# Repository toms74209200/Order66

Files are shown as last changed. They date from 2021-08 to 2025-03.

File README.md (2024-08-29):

Order66

<h1 style="text-align: center; margin-top: 0; margin-bottom: 7rem; border-bottom: none;">Order66 - 日本語入力のための60%キーボード</h1>

- 66 keys
- Cherry MX/Kailh Choc/Kailh Choc V2 key switch compatible
- USB type-C (USB2.0) interface
- On-Board CPU(ATmega32U4)

## Layout

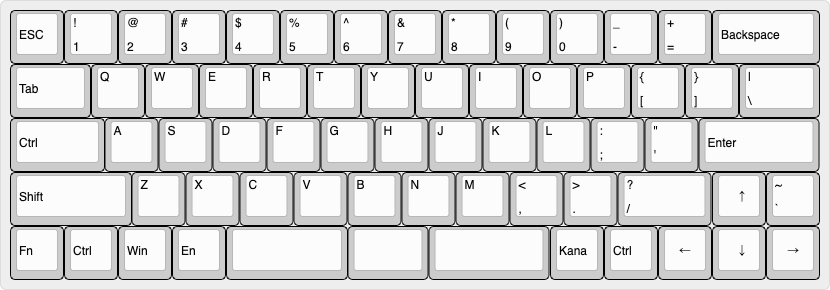
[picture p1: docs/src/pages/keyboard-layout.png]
layout


Designed in [Keyboard-layout-editor.com](http://www.keyboard-layout-editor.com).

## License

MIT License

## Author

[toms74209200](<https://github.com/toms74209200>)

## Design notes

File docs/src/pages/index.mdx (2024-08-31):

---
layout: ../layouts/Layout.astro
title: Order66 - 日本語入力のための60%キーボード
---
import { Image } from 'astro:assets';

import logoOrder66 from './logo_order66.svg';
import keyboardLayout from './keyboard-layout.png';
import landingImage from '../../public/landingview.webp';

<Image src={logoOrder66} alt="Order66" width={keyboardLayout.width} style="max-width: 100%;" />

<div style="max-width: 100%;">
  <h1 style="text-align: center; margin-top: 0; margin-bottom: 5rem">Order66 - 日本語入力のための60%キーボード</h1>
</div>

<div style="margin-top: 3rem; margin-bottom: 5rem;">
  サンプル画像
</div>

## キーマップ

キーマップ

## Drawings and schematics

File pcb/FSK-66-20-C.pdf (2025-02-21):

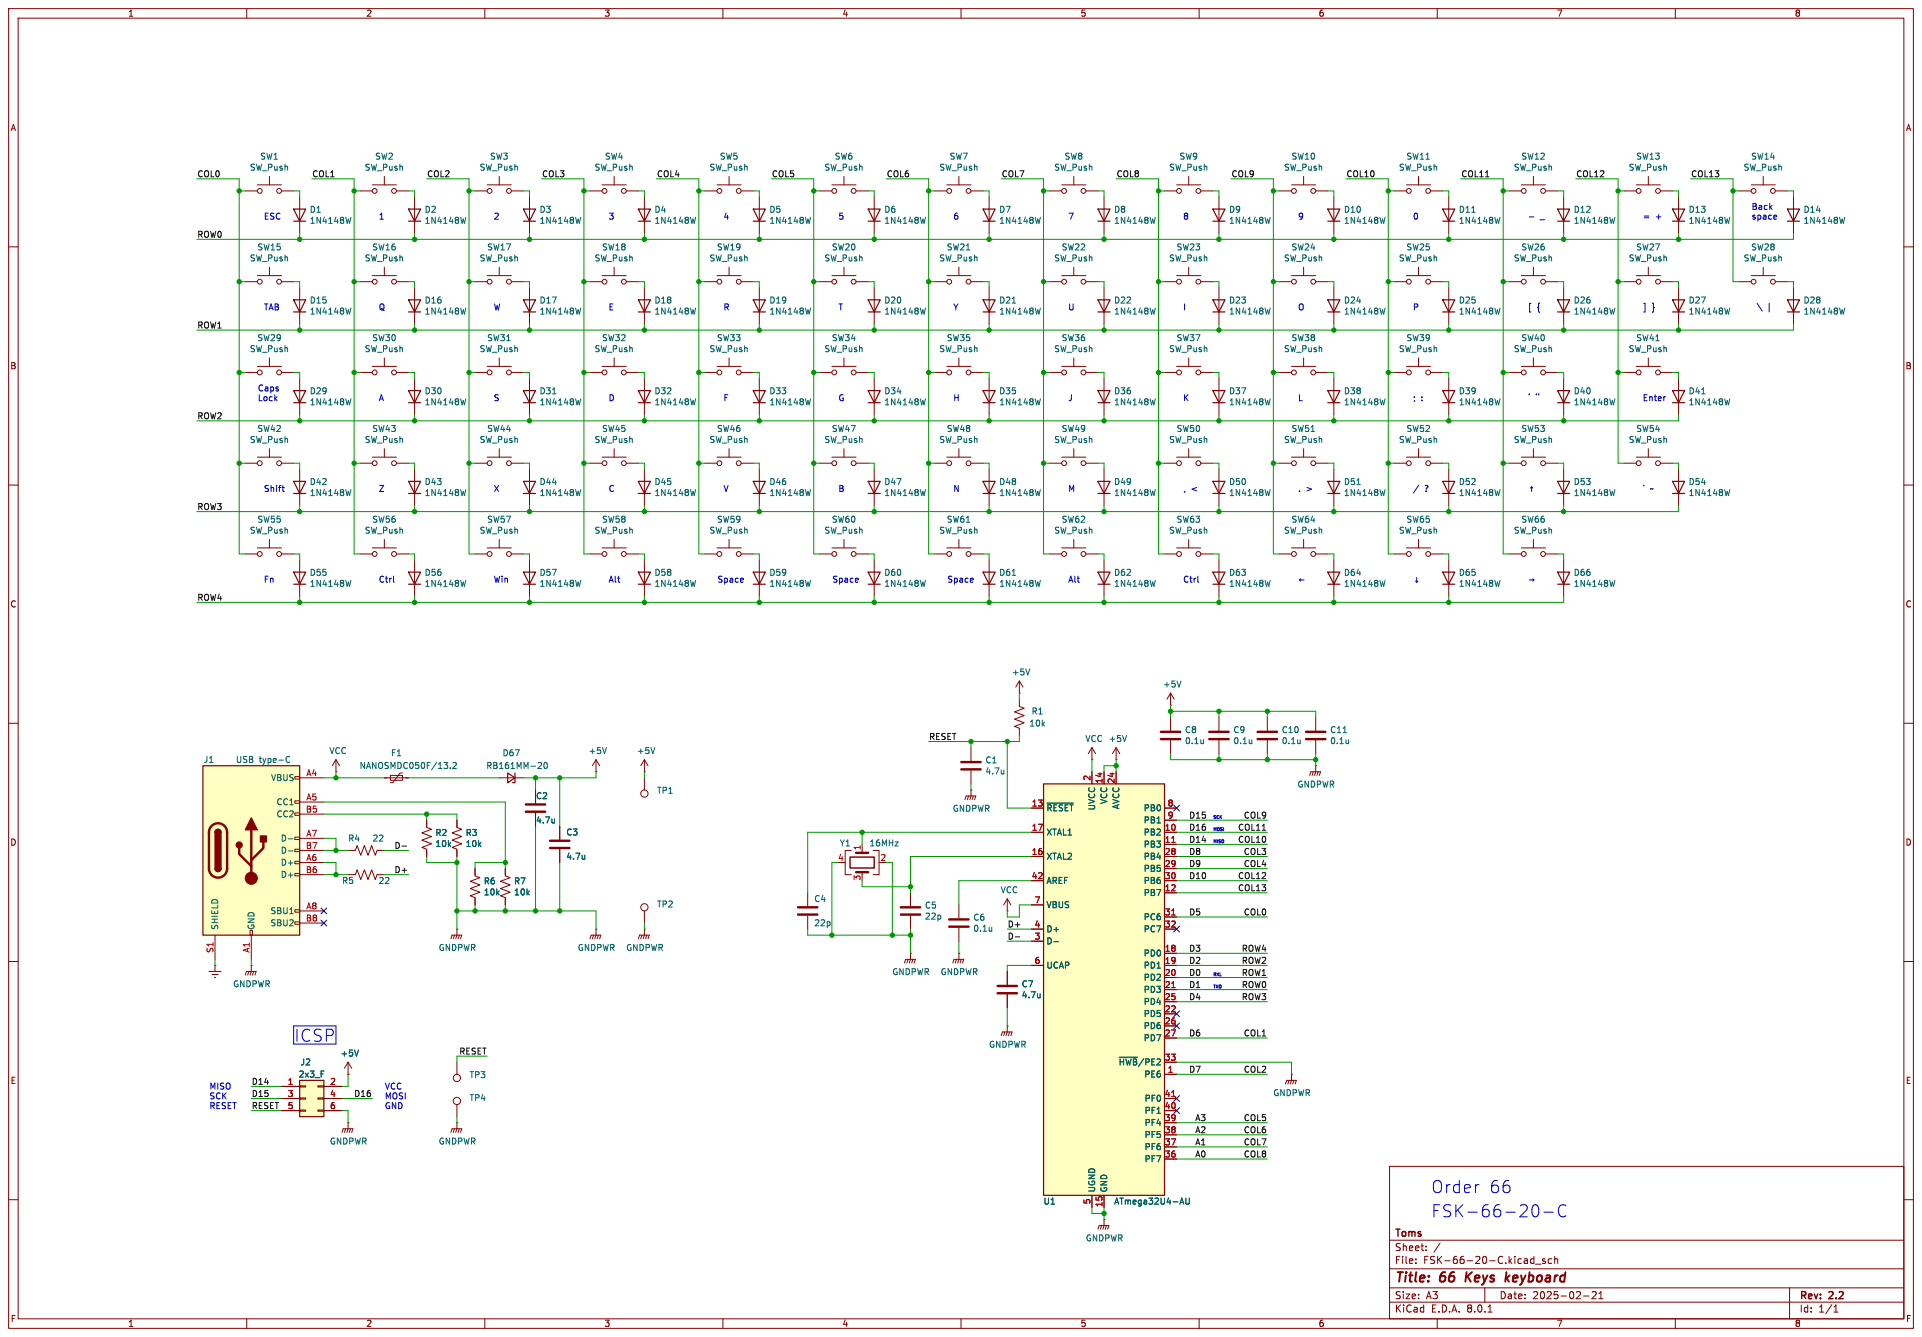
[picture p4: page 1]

2 PD2 20 PD3 21 PD5 22 AVCC 24 PD4 25 PD6 26 PD7 27 PB4 28 PB5 29 D- 3 PB6 30 PC6 31 PC7 32 ~{HWB}/PE233 PF7 36 PF6 37 PF5 38 PF4 39 D+ 4 PF1 40 PF0 41 AREF 42 UGND

5 UCAP 6 VBUS 7 PB0 8 PB1 9 U1 ATmega32U4-AU GNDPWR

Id: 1/1 Title: 66 Keys keyboard

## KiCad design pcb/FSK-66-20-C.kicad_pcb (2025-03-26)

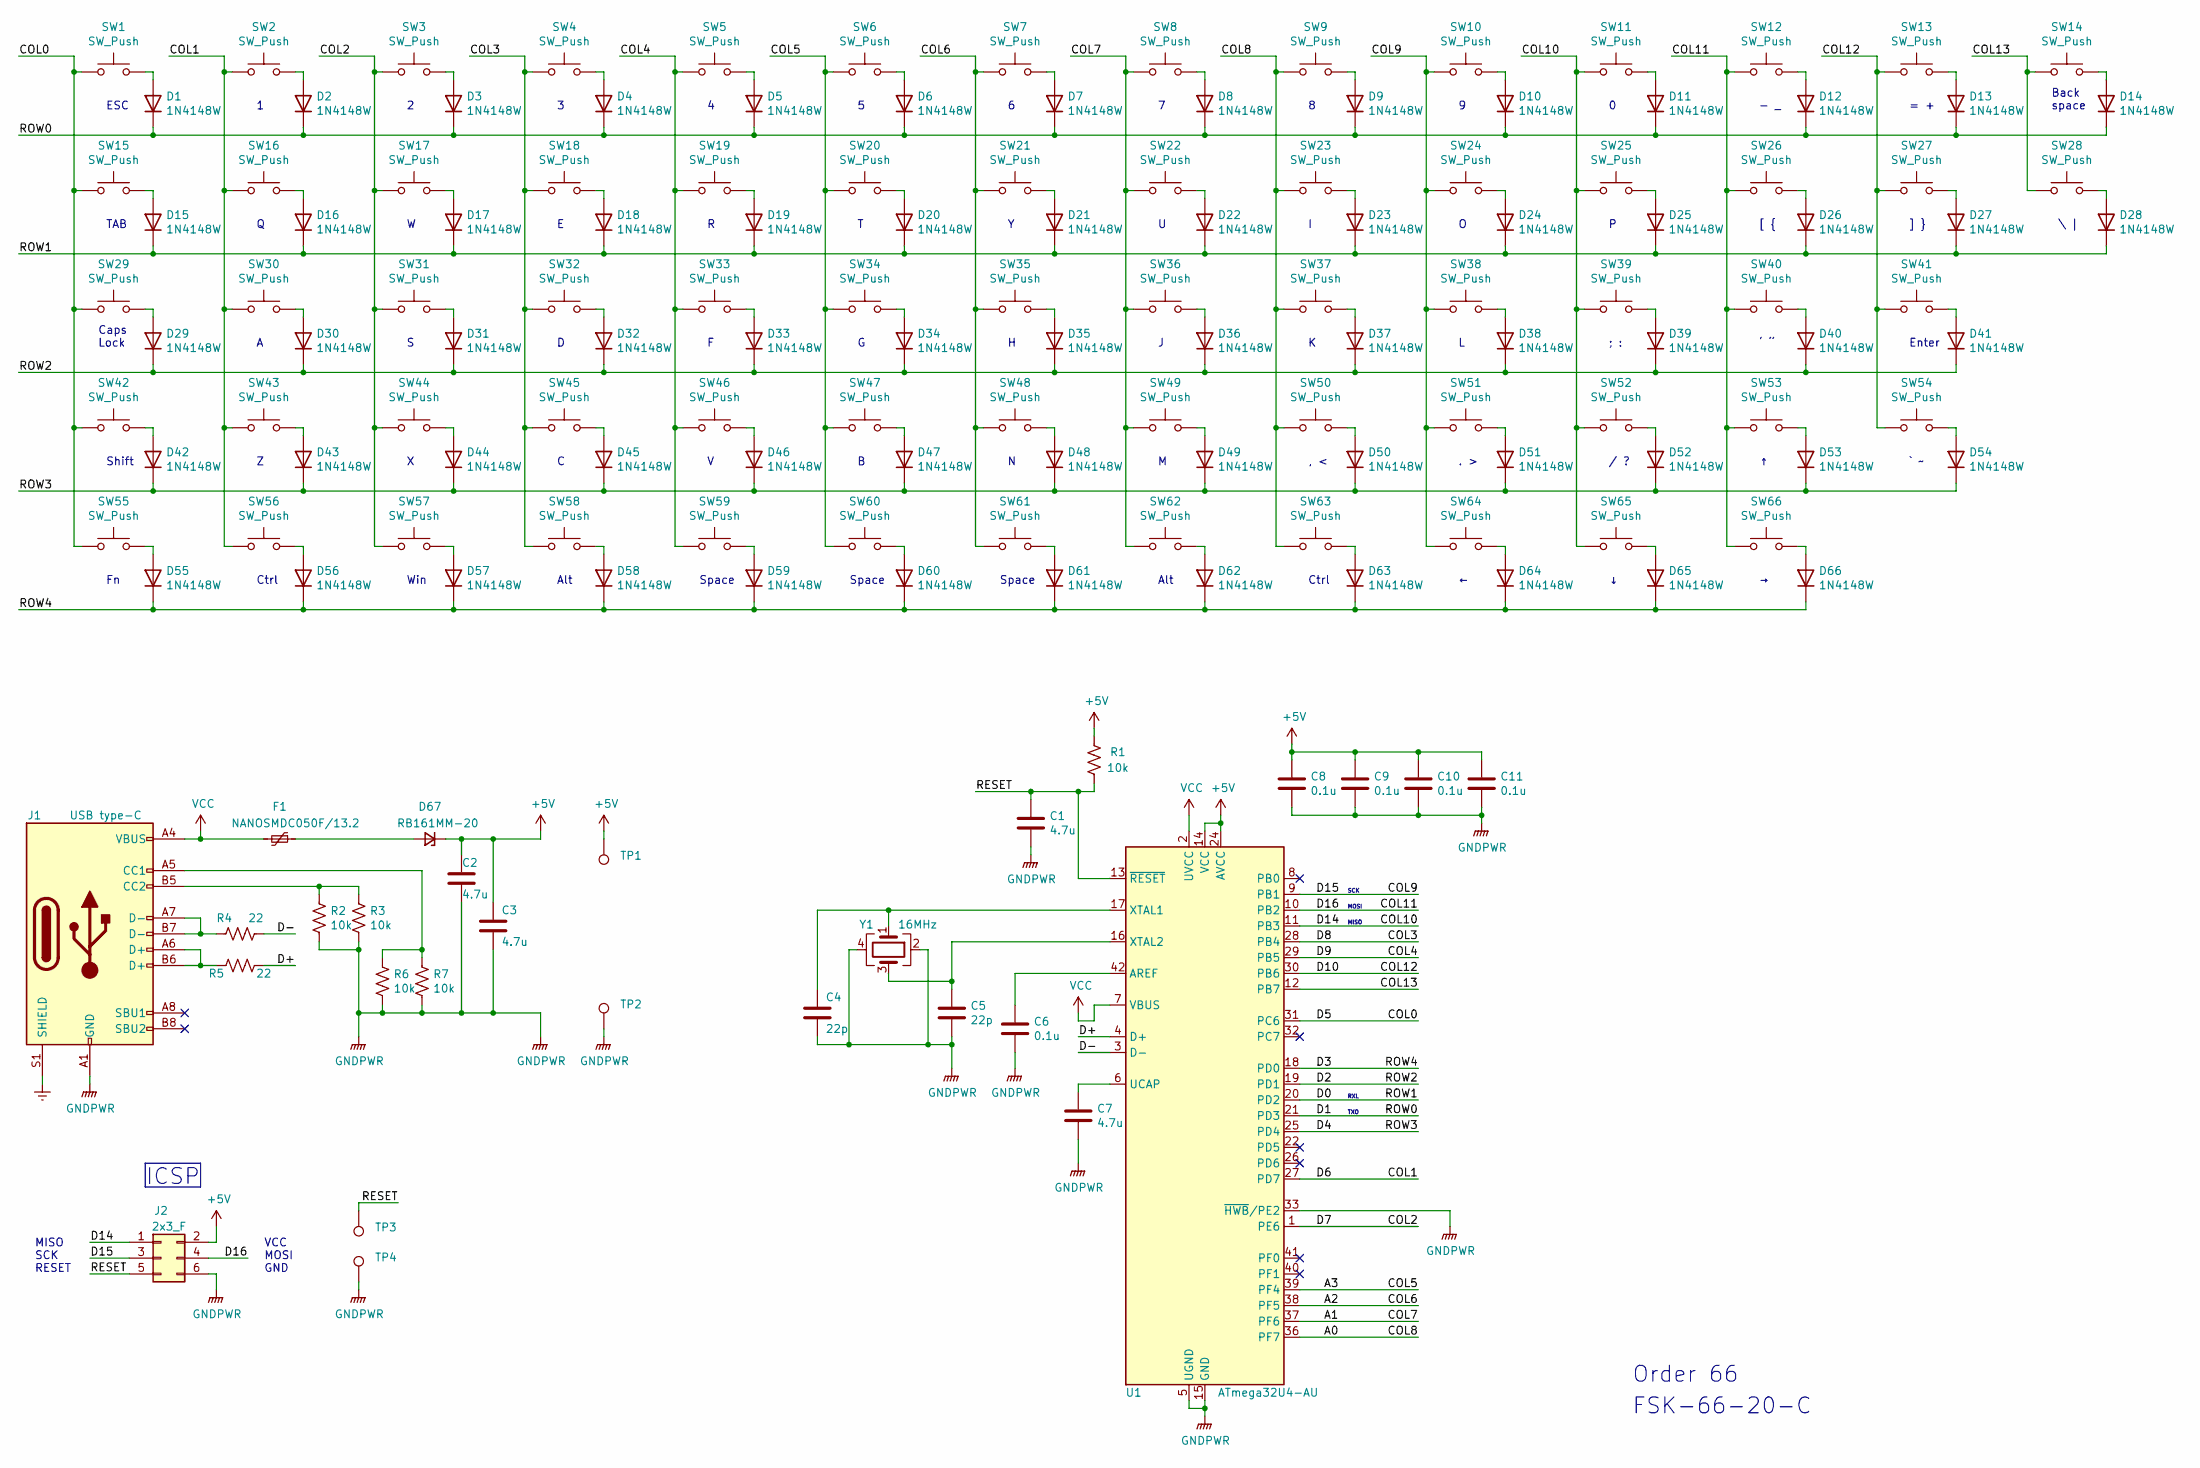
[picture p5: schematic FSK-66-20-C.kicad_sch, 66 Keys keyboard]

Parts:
C1, C2, C3, C7: 4.7u; C_0603_1608Metric
C4, C5: 22p; C_0402_1005Metric
C6, C8, C9, C10, C11: 0.1u; C_0402_1005Metric
D1, D2, D3, D4, D5, D6, D7, D8, D9, D10, D11, D12, D13, D14, D15, D16, D17, D18, D19, D20, D21, D22, D23, D24, D25, D26, D27, D28, D29, D30, D31, D32, D33, D34, D35, D36, D37, D38, D39, D40, D41, D42, D43, D44, D45, D46, D47, D48, D49, D50, D51, D52, D53, D54, D55, D56, D57, D58, D59, D60, D61, D62, D63, D64, D65, D66: 1N4148W; D_SOD-123
D67: RB161MM-20; D_SOD-123F
F1: NANOSMDC050F/13.2; Fuse_1206_3216Metric
J1: USB type-C; USB_C_Receptacle_Palconn_UTC16-G
J2: 2x3_F; PinHeader_2x03_P2.54mm_Vertical
R1, R2, R3, R6, R7: 10k; R_0402_1005Metric
R4, R5: 22; R_0402_1005Metric
SW1, SW2, SW3, SW4, SW5, SW6, SW7, SW8, SW9, SW10, SW11, SW12, SW13, SW14, SW15, SW16, SW17, SW18, SW19, SW20, SW21, SW22, SW23, SW24, SW25, SW26, SW27, SW28, SW29, SW30, SW31, SW32, SW33, SW34, SW35, SW36, SW37, SW38, SW39, SW40, SW41, SW42, SW43, SW44, SW45, SW46, SW47, SW48, SW49, SW50, SW51, SW52, SW53, SW54, SW55, SW56, SW57, SW58, SW59, SW60, SW61, SW62, SW63, SW64, SW65, SW66: SW_Push; CherryMX_Choc_V2_1u
TP1, TP2, TP3, TP4: TestPoint_THTPad_D1.0mm_Drill0.5mm
U1: ATmega32U4-AU; ATMEGA32U4-AU
Y1: 16MHz; Crystal_SMD_SeikoEpson_FA238-4Pin_3.2x2.5mm

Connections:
+5V: C2.1, C3.1, C8.1, C9.1, C10.1, C11.1, D67.1 (K), J2.2, R1.1, TP1.1, U1.14 (VCC), U1.24 (AVCC), U1.34 (VCC), U1.44 (AVCC)
/A0: SW9.1, SW23.1, SW37.1, SW50.1, SW63.1, U1.36 (PF7)
/A1: SW8.1, SW22.1, SW36.1, SW49.1, SW62.1, U1.37 (PF6)
/A2: SW7.1, SW21.1, SW35.1, SW48.1, SW61.1, U1.38 (PF5)
/A3: SW6.1, SW20.1, SW34.1, SW47.1, SW60.1, U1.39 (PF4)
/COL0: SW1.1, SW15.1, SW29.1, SW42.1, SW55.1, U1.31 (PC6)
/COL1: SW2.1, SW16.1, SW30.1, SW43.1, SW56.1, U1.27 (PD7)
/COL2: SW3.1, SW17.1, SW31.1, SW44.1, SW57.1, U1.1 (PE6)
/COL3: SW4.1, SW18.1, SW32.1, SW45.1, SW58.1, U1.28 (PB4)
/COL4: SW5.1, SW19.1, SW33.1, SW46.1, SW59.1, U1.29 (PB5)
/COL9: J2.3, SW10.1, SW24.1, SW38.1, SW51.1, SW64.1, U1.9 (PB1)
/COL10: J2.1, SW11.1, SW25.1, SW39.1, SW52.1, SW65.1, U1.11 (PB3)
/COL11: J2.4, SW12.1, SW26.1, SW40.1, SW53.1, SW66.1, U1.10 (PB2)
/COL12: SW13.1, SW27.1, SW41.1, SW54.1, U1.30 (PB6)
/COL13: SW14.1, SW28.1, U1.12 (PB7)
/D0: D15.1 (K), D16.1 (K), D17.1 (K), D18.1 (K), D19.1 (K), D20.1 (K), D21.1 (K), D22.1 (K), D23.1 (K), D24.1 (K), D25.1 (K), D26.1 (K), D27.1 (K), D28.1 (K), U1.20 (PD2)
/D1: D1.1 (K), D2.1 (K), D3.1 (K), D4.1 (K), D5.1 (K), D6.1 (K), D7.1 (K), D8.1 (K), D9.1 (K), D10.1 (K), D11.1 (K), D12.1 (K), D13.1 (K), D14.1 (K), U1.21 (PD3)
/D2: D29.1 (K), D30.1 (K), D31.1 (K), D32.1 (K), D33.1 (K), D34.1 (K), D35.1 (K), D36.1 (K), D37.1 (K), D38.1 (K), D39.1 (K), D40.1 (K), D41.1 (K), U1.19 (PD1)
/D3: D55.1 (K), D56.1 (K), D57.1 (K), D58.1 (K), D59.1 (K), D60.1 (K), D61.1 (K), D62.1 (K), D63.1 (K), D64.1 (K), D65.1 (K), D66.1 (K), U1.18 (PD0)
/D4: D42.1 (K), D43.1 (K), D44.1 (K), D45.1 (K), D46.1 (K), D47.1 (K), D48.1 (K), D49.1 (K), D50.1 (K), D51.1 (K), D52.1 (K), D53.1 (K), D54.1 (K), U1.25 (PD4)
/D+: R5.1, U1.4 (D+)
/D-: R4.1, U1.3 (D-)
/RESET: C1.1, J2.5, R1.2, TP3.1, U1.13 (~RESET)
Earth: J1.S1 (SHIELD)
GNDPWR: C1.2, C2.2, C3.2, C4.2, C5.2, C6.2, C7.2, C8.2, C9.2, C10.2, C11.2, J1.A1 (GND), J1.A12 (GND), J1.B1 (GND), J1.B12 (GND), J2.6, R2.2, R3.2, R6.2, R7.2, TP2.1, TP4.1, U1.5 (UGND), U1.15 (GND), U1.23 (GND), U1.33 (~HWB/PE2), U1.35 (GND), U1.43 (GND), Y1.2, Y1.4
unnamed: D1.2 (A), SW1.2
unnamed: D2.2 (A), SW2.2
unnamed: D3.2 (A), SW3.2
unnamed: D4.2 (A), SW4.2
unnamed: D5.2 (A), SW5.2
unnamed: D6.2 (A), SW6.2
unnamed: D7.2 (A), SW7.2
unnamed: D8.2 (A), SW8.2
unnamed: D9.2 (A), SW9.2
unnamed: D10.2 (A), SW10.2
unnamed: D11.2 (A), SW11.2
unnamed: D12.2 (A), SW12.2
unnamed: D13.2 (A), SW13.2
unnamed: D14.2 (A), SW14.2
unnamed: D15.2 (A), SW15.2
unnamed: D16.2 (A), SW16.2
unnamed: D17.2 (A), SW17.2
unnamed: D18.2 (A), SW18.2
unnamed: D19.2 (A), SW19.2
unnamed: D20.2 (A), SW20.2
unnamed: D21.2 (A), SW21.2
unnamed: D22.2 (A), SW22.2
unnamed: D23.2 (A), SW23.2
unnamed: D24.2 (A), SW24.2
unnamed: D25.2 (A), SW25.2
unnamed: D26.2 (A), SW26.2
unnamed: D27.2 (A), SW27.2
unnamed: D28.2 (A), SW28.2
unnamed: D29.2 (A), SW29.2
unnamed: D30.2 (A), SW30.2
unnamed: D31.2 (A), SW31.2
unnamed: D32.2 (A), SW32.2
unnamed: D33.2 (A), SW33.2
unnamed: D34.2 (A), SW34.2
unnamed: D35.2 (A), SW35.2
unnamed: D36.2 (A), SW36.2
unnamed: D37.2 (A), SW37.2
unnamed: D38.2 (A), SW38.2
unnamed: D39.2 (A), SW39.2
unnamed: D40.2 (A), SW40.2
unnamed: D41.2 (A), SW41.2
unnamed: D42.2 (A), SW42.2
unnamed: D43.2 (A), SW43.2
unnamed: D44.2 (A), SW44.2
unnamed: D45.2 (A), SW45.2
unnamed: D46.2 (A), SW46.2
unnamed: D47.2 (A), SW47.2
unnamed: D48.2 (A), SW48.2
unnamed: D49.2 (A), SW49.2
unnamed: D50.2 (A), SW50.2
unnamed: D51.2 (A), SW51.2
unnamed: D52.2 (A), SW52.2
unnamed: D53.2 (A), SW53.2
unnamed: D54.2 (A), SW54.2
unnamed: D55.2 (A), SW55.2
unnamed: D56.2 (A), SW56.2
unnamed: D57.2 (A), SW57.2
unnamed: D58.2 (A), SW58.2
unnamed: D59.2 (A), SW59.2
unnamed: D60.2 (A), SW60.2
unnamed: D61.2 (A), SW61.2
unnamed: D62.2 (A), SW62.2
unnamed: D63.2 (A), SW63.2
unnamed: D64.2 (A), SW64.2
unnamed: D65.2 (A), SW65.2
unnamed: D66.2 (A), SW66.2
unnamed: D67.2 (A), F1.1
unnamed: J1.A5 (CC1), R6.1, R7.1
unnamed: J1.B5 (CC2), R2.1, R3.1
unnamed: J1.A6 (D+), J1.B6 (D+), R5.2
unnamed: J1.A7 (D-), J1.B7 (D-), R4.2
unnamed: C6.1, U1.42 (AREF)
unnamed: C7.1, U1.6 (UCAP)
unnamed: C4.1, U1.17 (XTAL1), Y1.1
unnamed: C5.1, U1.16 (XTAL2), Y1.3
VCC: F1.2, J1.A4 (VBUS), J1.A9 (VBUS), J1.B4 (VBUS), J1.B9 (VBUS), U1.2 (UVCC), U1.7 (VBUS)

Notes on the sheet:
] }
Win
- _
Caps Lock
Alt
/ ?
TAB
MOSI
Ctrl
= +
Space
‘ “
TXO
\ |
ICSP
Enter
Order 66
SCK
MISO SCK RESET
Shift
; :
. >
ESC
RXL
` ~
, <
MISO
[ {
Back space
VCC MOSI GND
FSK-66-20-C

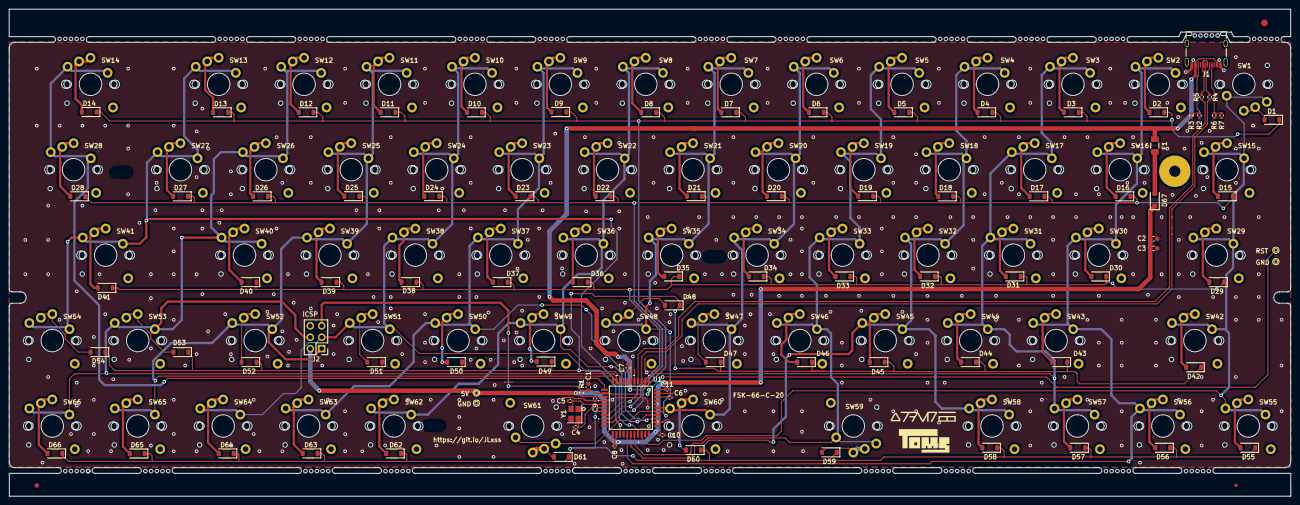
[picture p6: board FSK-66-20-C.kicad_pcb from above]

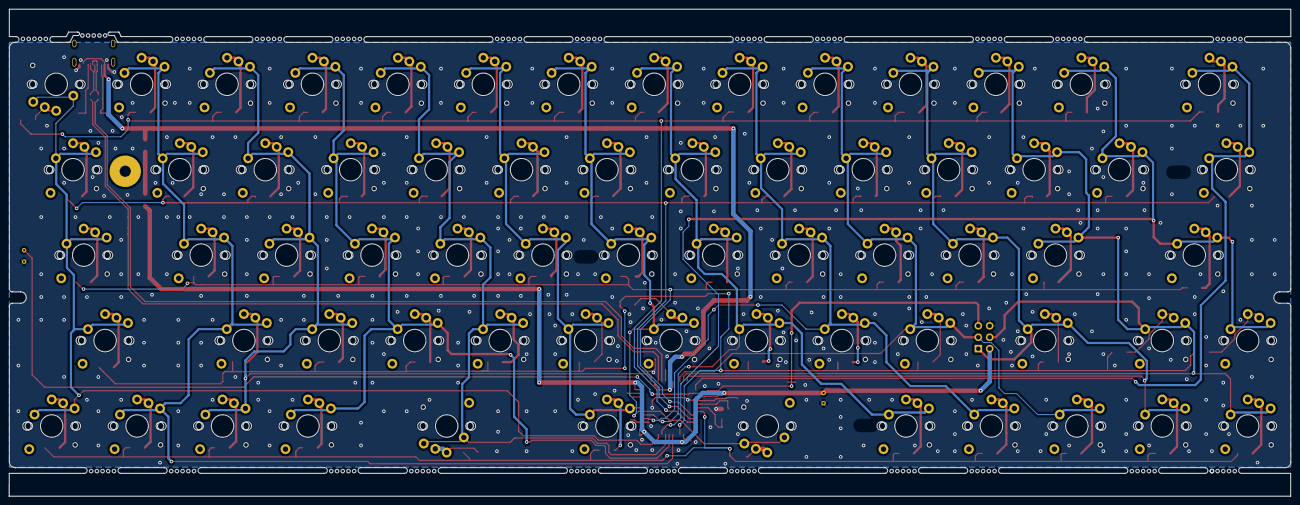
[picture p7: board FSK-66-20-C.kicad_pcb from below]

Board: 2 copper layers, 285.0 x 108.3 mm, 164 parts (66 on the bottom side), 100 nets.

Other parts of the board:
HOLE: VAL**; PKRH
HOLE#2, HOLE#3: VAL**; PKRH
HOLE#4: VAL**; PKRHC

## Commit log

2020-12-29 [add]add schematic
    [FSK-66-20-C.sch]
2020-12-30 [fix]fix connection of CC2
    [FSK-66-20-C.sch]
2020-12-31 [fix]fix cross connection
    [FSK-66-20-C.sch]
2021-01-02 [fix]fix COL1 connection
    [FSK-66-20-C.sch]
2021-01-07 [add]add PCB
    [FSK-66-20-C.kicad_pcb]
2021-01-11 [change]change side holes to no-plated
    [FSK-66-20-C.kicad_pcb]
2023-12-29 [change]change artwork
    [FSK-66-20-C.kicad_pcb, FSK-66-20-C.kicad_sch]
2024-01-20 [change]update artwork for board drill
    [FSK-66-20-C.kicad_pcb]
2024-05-19 :sparkles: Update schematic
    [FSK-66-20-C.kicad_sch]
2024-05-19 :fire: Remove old version files
    [FSK-66-20-C.sch]
2024-05-26 :sparkles: Update PCB
    [FSK-66-20-C.kicad_pcb, FSK-66-20-C.kicad_sch]
2024-06-05 :sparkles: Add switch plate
    [order66_switch_plate.kicad_pcb]
2024-09-19 :sparkles: Update PCB for Kailh Choc stabilizer
    [FSK-66-20-C.kicad_pcb]
2024-09-20 :sparkles: Update switch plate for Kailh Choc stabilizer
    [order66_switch_plate.kicad_pcb]
2024-10-06 :sparkles: Add middle plate
    [order66_middle_plate.kicad_pcb, order66_switch_plate.kicad_pcb]
2024-10-06 :sparkles: Update top key switch plate
    [order66_switch_plate.kicad_pcb]
2025-03-25 :sparkles: Update middle plate
    [order66_middle_plate.kicad_pcb]
2025-03-25 :sparkles: Update top plate
    [order66_switch_plate.kicad_pcb]
